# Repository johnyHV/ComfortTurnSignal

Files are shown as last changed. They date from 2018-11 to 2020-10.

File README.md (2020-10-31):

# ComfortTurnSignal

This project is default use for VW Golf MK4 comfort turn signal. 
Schematic and source code it can also be used in another car without comfort turn signal.

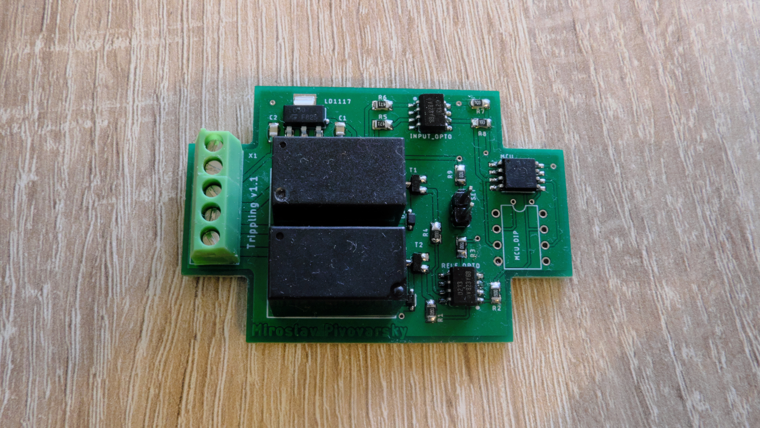
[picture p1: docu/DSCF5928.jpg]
Image description


Youtube video

IMAGE ALT TEXT HERE (https://www.youtube.com/watch?v=xPU7Pdd0vOQ)

# Change log

Version 1.2.1
- HW version 1.2
- SW version 1.4.1

Version 1.2
- HW version 1.2
- SW version 1.4.0

Version 1.1
- HW version 1.1
- SW version 1.3

# Change log SW

Version 1.4.1
- added function, for change blink interval, if is jumper set. Function for this featchure is CheckBlinkIntervalJumper. But if is this function enabled in main.c, then must be definition EEPROM_ENABLE set to 0

Version 1.4.0
- added conf.h file with global MCU configuration
- added debounce time for self calibration SET jumper

Version 1.3.0
- added featchure for disable trippling, when pressing the turn signal control for the opposite direction of flashing

Version 1.2.0
- added fix time for blinking from FLASH memmory

Version 1.1
- Fix bug

Version 1.0
- Init version

# Change log HW

Version 1.2
- update MCU connection
- added SPI programming connector
- added 100nF capacitor for MCU
- added description on the PCB

Version 1.1
- fixed problem with PCB design

Version 1.0
- first version

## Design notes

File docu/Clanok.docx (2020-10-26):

# Trippling – modul komfortného blikania smerových svetiel v aute

Trippling je moderná funkcionalita komfortného blikania smerových svetiel vozidla. Po krátkom stlačení páky smerových svetiel jednotka automaticky 3x blikne daným smerovým svetlom. Elektronika je navrhnutá ako prídavný modul k existujúcemu zapojeniu v automobile, s veľmi jednoduchým zapojením.

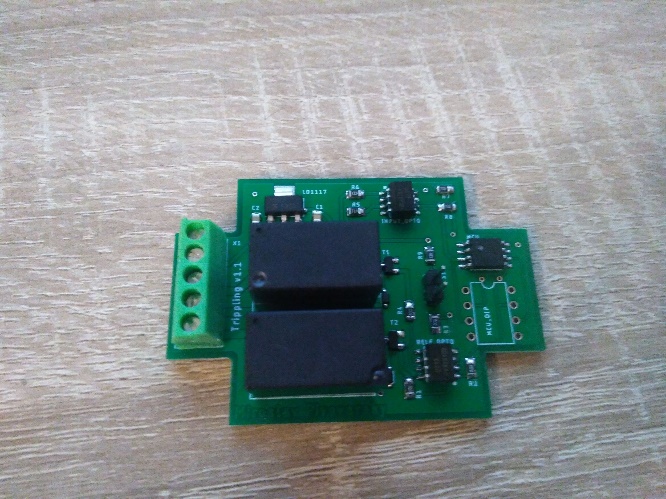
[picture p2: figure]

# Popis

Elektronika v zariadení využíva 5 pinov. Základné piny sú napájanie a zem. Ďalej sú to vstupno / výstupné piny pravého a ľavého smerového svetla a ich COM, čiže spoločný pin. Ak je zaznamenané napätie na ľavom alebo pravom smerovom svetle po určitý časový okamih, elektronika to vyhodnotí ako príkaz pre dokončenie trojitého blikania. Tie isté piny, ktoré detegujú napätie na smerovom svetle, sú použité aj pre spínanie smerových svetiel. Časovač zopnutia smerových svetiel pre trojité blikanie ovláda priamo MCU.

V článku použijem fotografie osadenej HW verzie 1.1, avšak opisovať budem HW verziu 1.2. V HW verzii 1.2 je pridaný blokovací kondenzátor pre MCU, pridaný ISP konektor pre pohodlnejšie programovanie MCU a sú vymenené piny procesora pre spínanie relé, s pinmi procesora, ktoré sledujú stav smerových svetiel. Táto úprava bola potrebná, aby bolo možné naprogramovať osadený MCU na PCB.

# Hardware

Samotné zapojenie pozostáva z MCU ATtiny85, dvoch optočlenov, dvoch RELE a stabilizátora napätia. ATtiny85 je jednoduchý 8 nožničkový MCU s 6 digitálnymi vstupmi/výstupmi, taktovacou frekvenciou 20Mhz bez potreby externého kryštálu. Ďalej obsahuje 8kB Flash pamäte, 512B RAM pamäte a 512B EEPROM pamäte. V tomto MCU vieme vypnúť RESET pin, a využiť ho ako štandardný vstupno/výstupný pin. Potom už musíme MCU programovať pomocou „High voltage programming“ rozhrania.

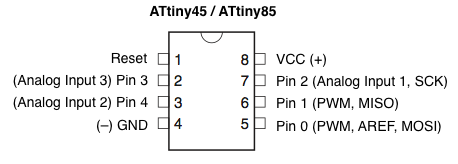
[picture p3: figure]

Návrh PCB je prispôsobený tak, aby všetky SMD súčiastky boli osadené z jednej strany. Pri takomto uložení súčiastok môžeme pre prispájkovanie súčiastok k PCB použiť napríklad žehličku. Spájkovanie žehličkou som opisoval v tomto článku (https://www.elektrolab.eu/blog/osadzanie-smd-suciastok-v-domacom-prostredi-pomocou-zehlicky). Pre nanášanie spájkovacej pasty môžeme použiť podávač spájkovacej pasty. Konštrukciu pre podávač som opísal v tomto článku (https://www.elektrolab.eu/blog/podavac-spajkovacej-pasty-solder-paste-dispenser).

Zoznam súčiastok:

- Attiny85 SOIC8 alebo DIP8 puzdro
- Stabilizátor LD1117 5V, SOT223 puzdro
- 2x optočlen ILD213T, SOIC puzdro
- 2x tranzistor MMBT3904, SOT23 puzdro
- 2x dióda 1N4148, SOD323F puzdro
- 2x relé HF32F/005-ZS, 5V a 5 pinové! (na Slovensku ho predáva napríklad avelmak.sk)
- 4x SMD rezistor 120ohm 0805
- 3x SMD rezistor 10Kohm 0805
- 2x SMD rezistor 470ohm 0805
- 3x SMD kondenzátor 100nF 0805
- 1x 5 pinový konektor PHOENIX 1751277, rozteč 3.5mm (alebo kombinácia 2 pinového a 3 pinového konektora)
- Krabička typu Z-24BU (známa aj ako KPZ 01 AU)

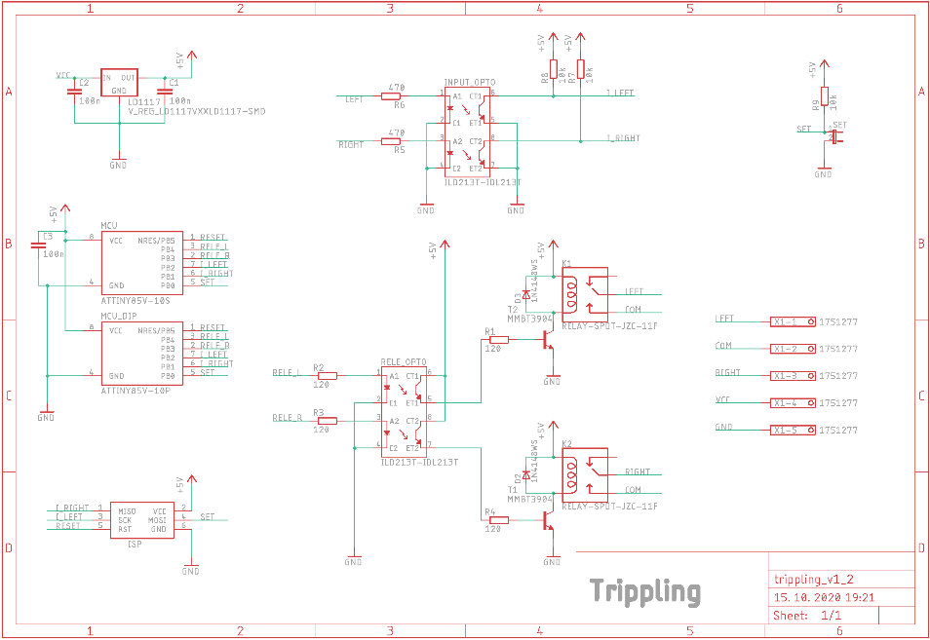
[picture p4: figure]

Schéma zapojenia

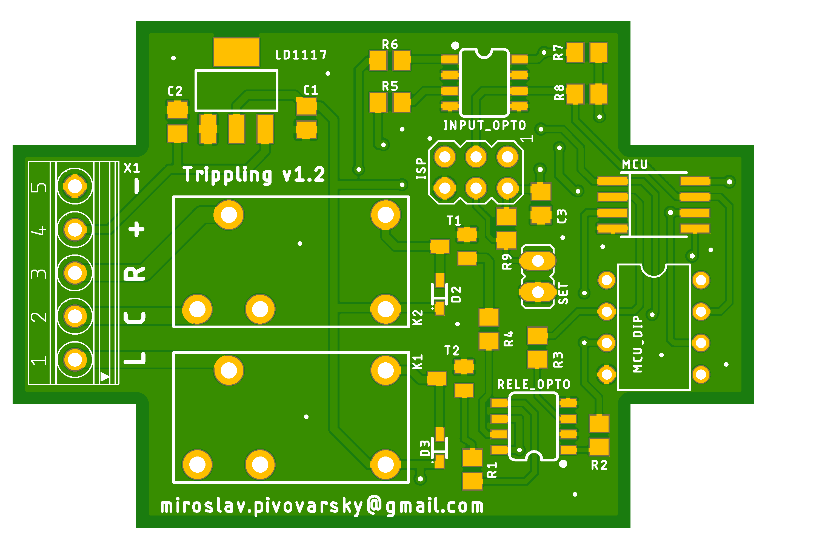
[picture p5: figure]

Vrchná strana PCB

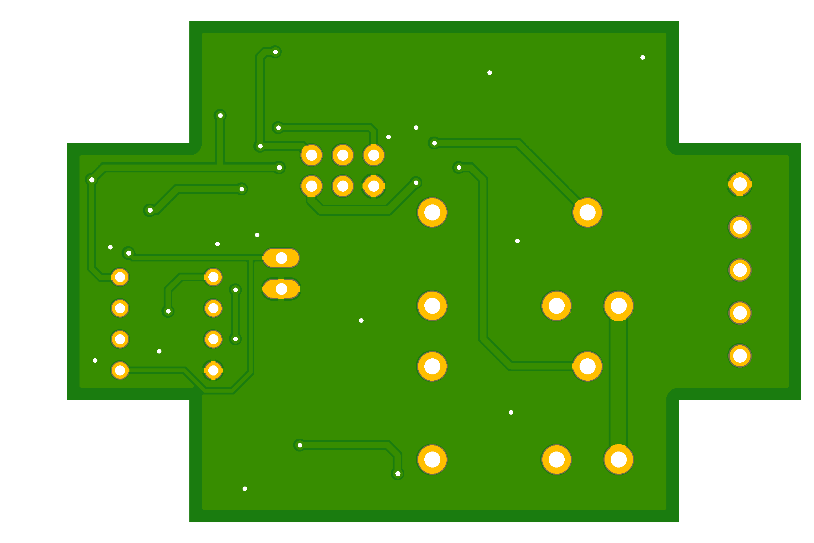
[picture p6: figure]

Spodná strana PCB

# Zapojenie

Pre napájanie elektroniky slúžia piny 4 a 5, označené plus a mínus z konektora X1. Maximálne napájacie napätie je 15V a absolútne maximálne napájacie napätie je 20V. To je pre elektroinštaláciu v bežnom aute postačujúci rozsah. Keďže ideme do automobilu pridať elektroniku neschválenú výrobcom, potrebujeme dodržať pár podmienok, aby sme predišli prípadným problémom počas technickej kontroly STK. Prvou podmienkou je pripojiť elektroniku cez vlastnú poistku. Poistka nemusí byť ľahko prístupná v prípade, že ju bude potrebné vymeniť. Druhá podmienka je, aby bolo možné vzpnúť elektroniku kedykoľvek a jednoducho. Na to je ideálny vypínač, ktorý je v dosahu ruky aj počas jazdy autom. Osobne testujem HW a SW už 2 roky, a funguje bez problémov. Nikto by si určite neželal, aby mu z ničoho nič začali blikať smerové svetlá vďaka HW/SW chybe, a nemohol to žiadnym spôsobom vypnúť. Práve z tohto dôvodu je vhodné mať vypínač vždy na dosah ruky. Ja som umiestnil vypínač zo spodnej strany palubnej dosky, blízko vodičových dverí. Vypínač je na prvý pohľad ukrytý, a súčasne vždy ľahko prístupný aj počas jazdy. Z danej poistky a vypínača, je v mojom prípade súčasne napájaná palubná kamera, cúvacia kamera a elektronika komfortného blikania. Odporúčam elektroniku pripojiť na vetvu KL15, čo je vetva, na ktorej sa objaví 12V až po otočení kľúča do prvej polohy.

Keď už máme elektroniku napájanú, ďalej je potrebné pripojiť elektroniku k smerovým svetlám. Nie je možné napísať univerzálne zapojenie pre všetky typy automobilov, keďže každý automobil ma iné farebné značenie kabeláže, a inú konštrukciu. Ja opíšem moje zapojenie, pre VW Golf 4, no myslím si, že by to malo sedieť pre automobily z koncernu VW Group.

Prvým krokom bolo rozobrať stredový výduch. Skrutky sa ukázali po vybratí plastov, pre smerovanie vyfukovaného vzduchu. Odporúčam dať pozor na gumičky, ktoré sa nachádzajú na výduchoch po oboch stranách. Môže sa stať, že gumičky zapadnú dozadu. Bolo by lepšie mať pri manipulácií s nimi tie výduchy zatvorené. Následne som musel jemne odbaliť kabeláž pre výstražné svetlá, a nájsť správne vodiče.

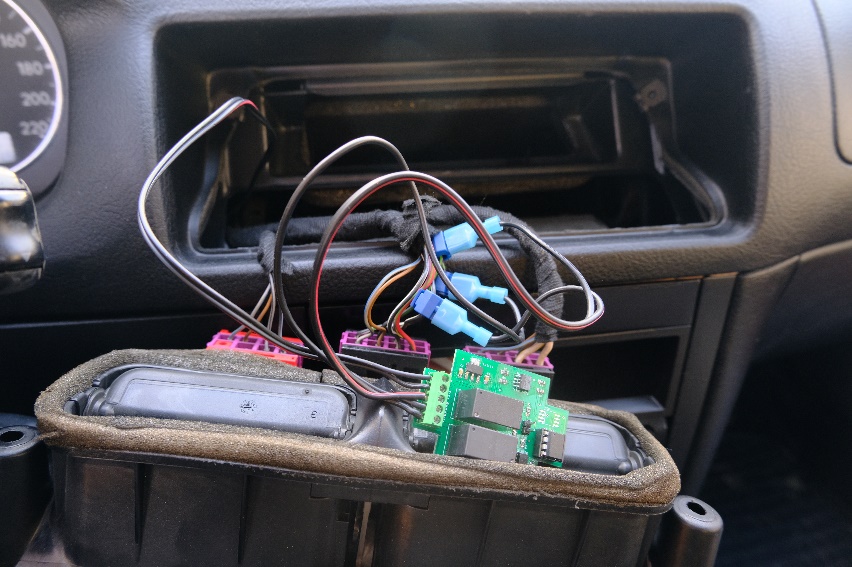
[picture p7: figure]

Pre zapojenie potrebujeme vodič pre ľavé aj pravé smerové svetlo, a ich spoločný vodič. Spoločný vodič je 12V napájacie napätie privedené z poistky pre smerové svetlá z poistkovej skrinky. To platí iba vo vozidlách s kladným ovládacím napätím smerových svietidiel a celej elektroinštalácie v aute. Zariadenie je možné použiť aj vo vozidle so záporným ovládacím napätím, keďže relé spína COM port voči príslušnému smerovému svetlu. Všetky tieto vodiče sa nachádzajú napríklad pri výstražnom tlačidle. Preto som zvolil možnosť pripojenia elektroniky k výstražnému tlačidlu. Súčasne je k výstražnému tlačidlu dotiahnutých 12V pre vetvu KL15 (napájanie na vodiči je až v prvej polohe kľúčika v spínacej skrinke) a zem, no ja som ich nevyužil. V aute mám vlastnú vetvu s 12V napájaním cez poistku a vypínač.

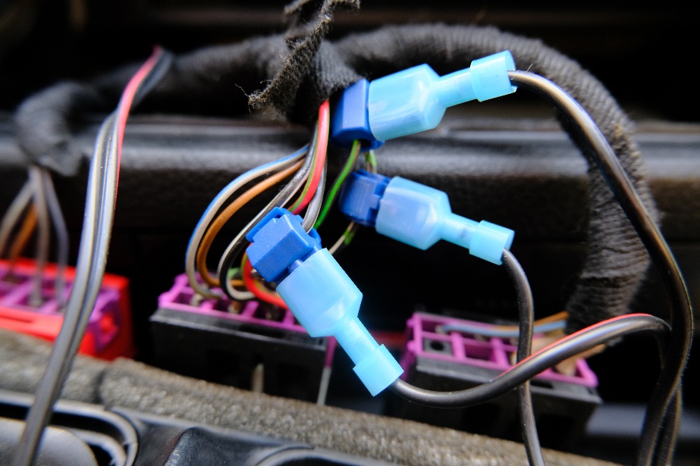
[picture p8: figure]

V nasledujúcej tabuľke opíšem význam farieb vodičov, a ich piny na výstražnom tlačidle pre Golf 4, čo by malo sedieť pre väčšinu áut daného koncernu medzi rokmi 1999-2005.

| Ľavá smerovka | Pravá smerovka | Spoločný kontakt | +12V | ZEM
Farba vodiča | Čierno biely | Čierno zelený | Čierno bielo zelený | Čierno biely | Hnedý
Číslo pinu na spínači | 3 | 2 | 1 | 7 | 6

Pre pripojenie k existujúcej kabeláži som sa snažil využiť najmenej deštruktívnu, a najľahšie rozoberateľnú možnosť. Použil som „T-TAP faston“ konektory. V čínskych e-shopoch sa dajú kúpiť dosť lacno, zvyčajne pod názvom „Snap Splice Lock Wire Terminal Crimp“. Na jednej strane je bočník s nožom, do ktorého sa pripája klasický faston konektor.

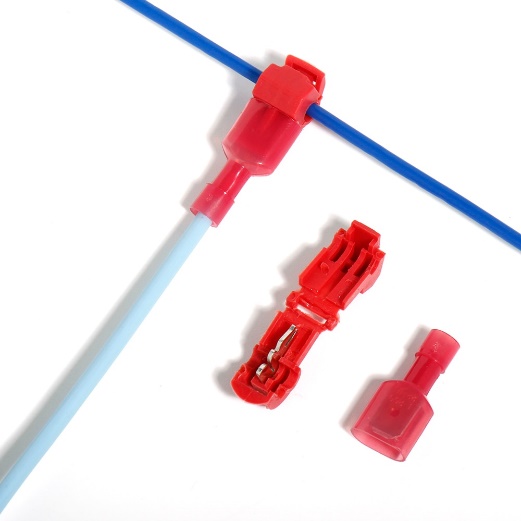
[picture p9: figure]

Vstup a výstup pre ľavú smerovku je na PCB označený písmenom L, pod číslom 1. Vstup a výstup pre pravú smerovku je označený na PCB písmenom R, pod číslo 3. Ako posledný ostal spoločný vodič, čiže COM. Ten je označený písmenom C, pod číslom 2.

Celá elektronika je navrhnutá tak, aby sa zmestila do spomínanej krabičky Z-24BU.

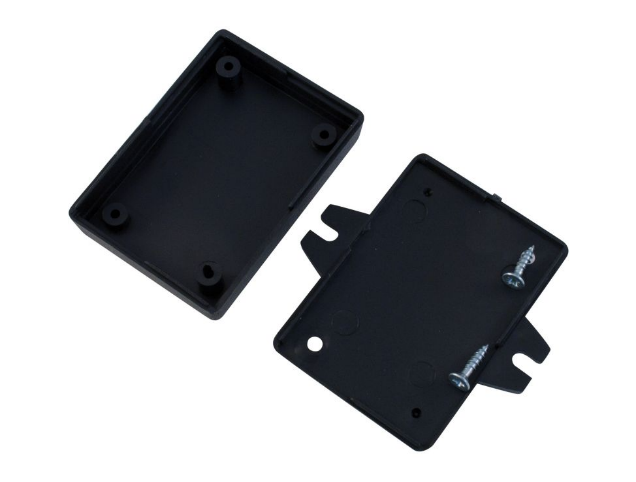
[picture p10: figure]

Po pripojení napájania na pin 4 a uzemnenia cez pin 5, je elektronika ihneď funkčná a aktívna. Procesor neprechádza do žiadneho sleep módu, a nie je v ňom naprogramovaný žiadny power save mód. Preto odporúčam pripojiť elektroniku na vetvu KL15, aby bola elektronika aktívna až po vložení kľúča a pretočení do prvej polohy.

# Ovládanie

Ak je elektronika napájaná, potom automaticky neustále monitoruje smerové svetla. Pre aktiváciu trojitého blikania musíte krátko ťuknúť do páky pre aktiváciu smerového svetla. Pri krátkom ťuknutí elektronika vyhodnotí rozkaz, pre aktiváciu trojitého bliknutia. V prípade, že ste aktivovali trojité blikanie, a rozhodli ste sa zrušiť svoju voľbu, krátko ťuknite do páky pre opačný smer, čím vydáte procesoru príkaz pre núdzové ukončenie jeho činnosti. Elektronika sleduje dĺžku „ťuknutia“ do páky pre smerové svetlá, t.j. sníma dĺžku impulzu pre aktiváciu povelu. V prípade, že sú smerové svetlá zapnuté nad určitý čas (pre príklad viac ako 300ms), procesor to vyhodnotí ako spínanie prerušovačom, ktorý vložil do automobilu výrobca. Z toho dôvodu, aby nezasahoval do oficiálneho cyklovača nevykoná žiadnu operáciu. Takáto situácia môže vzniknúť napríklad pri zapnutí výstražných svetiel, alebo v prípade, keď je páka smerového svetla aretovaná (zapnutá) trvale.

# Software

Zdrojový kód je napísaný v jazyku C, v Atmel Studio 7.0. Existujú 2 verzie zdrojového kódu. Aby si nemusel každý kompilovať zdrojový kód, pridám vykompilované binárne súbory pre oba verzie zdrojového kódu. V MCU je aktivovaný watchdog časovač, pre prípadné problémy.

Prvá verzia pracuje s možnosťou naučenia sa dĺžky zopnutia smerových svietidiel a následné uloženie hodnoty do EEPROM pamäte. Táto možnosť sa mi úplne neosvedčila. V jednom prípade sa mi stala situácia, kedy sa EEPROM pamäť prepísala. Mohlo sa to stať zákmitom, na jumpri počas štartovania auta. Aktuálne je už jumper ošetrený proti zákmitu. V tejto verzii zdrojového kódu odpojíme elektroniku od napájania, prepojíme jumper SET prepojkou, pripojíme napájacie napätie na elektroniku. Následne zapneme smerové svetlá pre ľavú stranu. Necháme chvíľu blikať smerové svetlá, a potom ich vypneme. Následne vypneme napájacie napätie pre elektroniku, a vyberieme prepojku pre jumper SET. Touto sekvenciou sme elektroniku naučili časový interval blikania prerušovača v automobile. Tento firmware nájdete pod názvom trippling_self_calibration_v1_4_0.hex

V druhej verzii si nastavíme fixnú hodnotu dĺžky zapnutia smerových svetiel, a pomocou tejto hodnoty skompilujeme zdrojový kód. Vďaka tomu sa stane hodnota konštantou, uloženou vo FLASH pamäti, ktorá je v princípe neprepisovateľná (neberiem v úvahu extrémne situácie). Tento firmware nájdete pod názvom trippling_fix_time_v1_4_0.hex, s pevne definovaným časom dĺžky zapnutia smerových svetiel 400ms a trojitým blikaním. V tomto zdrojovom kóde musí byť ťuknutie do páky pre smerové svetlá dlhšie ako 80ms ale kratšie ako 300ms.

V zdrojovom kóde sa nachádza súbor Conf.h pre konfiguráciu MCU a jednotlivých funkcionalít. Definícia BLINK_INTERVAL určuje počet bliknutí, aktuálne je táto hodnota nastavená na 3 bliknutia, ale môžete si ju nastaviť na ľubovoľný počet. Dĺžku času, kedy je celé zariadenie neaktívne po núdzovom vypnutí môžeme nastaviť pomocou premennej SAFETY_DELAY, ktorá je aktuálne nastavená na 500ms. Dĺžku zopnutia a vypnutia smerových svetiel počas blikania môžeme nastaviť v zdrojovom kóde pomocou premennej TIME_ON_OFF_LENGTH. Táto premenná sa používa iba v tom prípade, kedy využívate pevne nastavený čas blikania z FLASH pamäte. V prípade, že chcete používať EEPROM pamäť pre dynamickú zmenu dĺžky blikania, je potrebné v súbore Conf.h nastaviť definíciu EEPROM_ENABLE na hodnotu 1. Časový interval, počas ktorého ak buchneme do páky pre smerové svetlá, bude aktivované trojité blikanie, je vypočítaný automaticky na 80% z času blikania v prípade, ak použijete EEPROM pamäť. Ak použijete pevnú definíciu vo FLASH pamäti, potom tieto intervaly môžeme nastaviť pomocou definícií TIMEOUT_ENABLE_BULB a MIN_TIME_FOR_EN_TRIPP. Pričom definícia TIMEOUT_ENABLE_BULB vraví o maximálnej dĺžke zopnutia páky, v tomto prípade 300ms a definícia MIN_TIME_FOR_EN_TRIPP vraví o minimálnej dobe zopnutia páky, v tomto prípade 80ms. Minimálna doba je pridaná z dôvodu auto diagnostiky vypálenej žiarovky v niektorých automobiloch.

Nastavenie poistiek pre MCU ATtiny85 je následovné:

Extended: 0xFF

HIGH: 0xD7

LOW: 0xE2

LOCKBIT: 0xFF

Prikladám aj screenshoty nastavenia poistiek z AVR štúdia

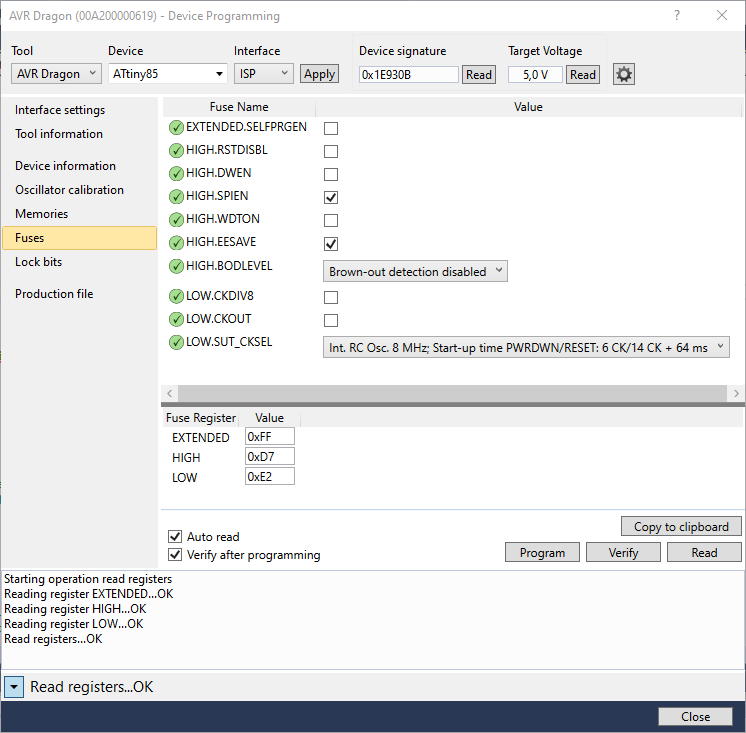
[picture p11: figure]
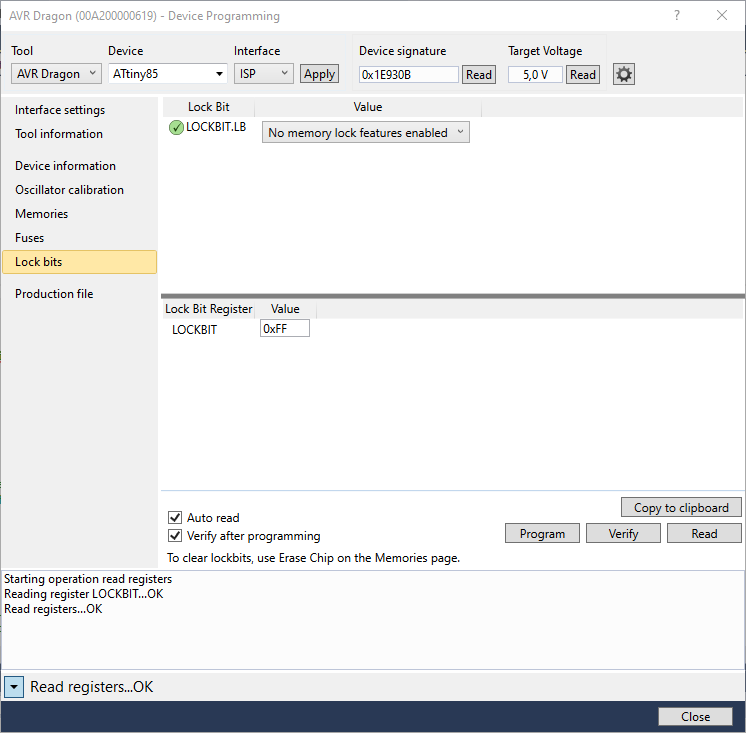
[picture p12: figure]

Pre nahratie binárneho súboru môžete použiť napríklad AVRDUDE v kombinácii s AVRDUDESS. AVRDUDE je konzolový SW pre nahrávanie binárneho súboru pomocou programátora do MCU, a AVRDUDESS je grafická nadstavba pre AVRDUDE. Môžeme ho stiahnuť napríklad zo stránky https://blog.zakkemble.net/avrdudess-a-gui-for-avrdude/ . Ako programátor používam USBasp debuger k AVRDUDE a AVR dragon k atmel studiu. AVR dragon podporuje rozšírené možnosti, napríklad možnosť debugovania SW v bežiacom MCU. USBasp je lacný programátor, ktorý viete kúpiť aj v čínskom e-shope alebo si ho vyrobiť pomocou Arduina. Osobne sa mi z lacných programátorov najviac osvedčil USBasp programátor pre Atmel MCU. Nastavenie AVRDUDESS by v tomto prípade vyzeralo následovne:

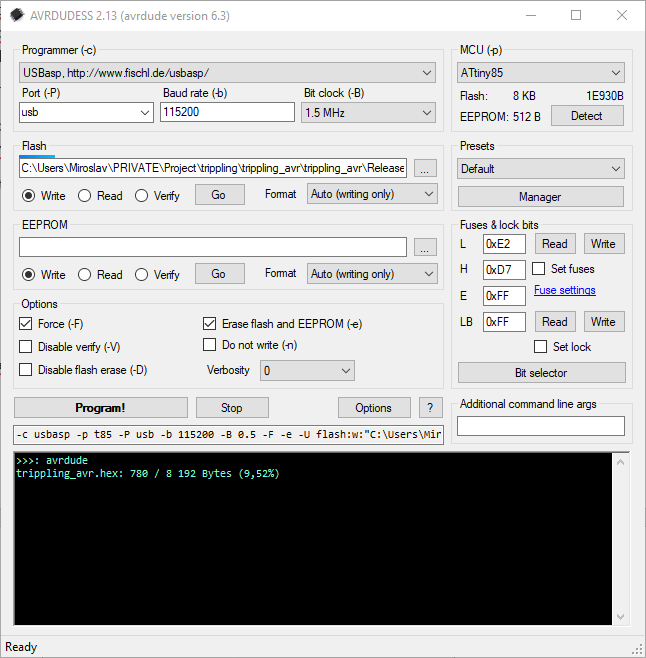
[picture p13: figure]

Niekedy sa môže stať, že pri kúpe nového procesora ATtiny85 ho musíme prvý krát pripojiť pomocou rozhrania „High Voltage programming“ k programátoru, a nastaviť mu správne poistky. Vytvoriť si vlastný „High voltage“ programátor je už trochu náročnejšie, práve preto využívam originálny programátor AVR dragon. V prípade záujmu viem upraviť konfiguráciu zdrojového kódu podľa požiadaviek, a nahrať vykompilovaný zdrojový kód do MCU ATtiny85. Toto zapojenie viete použiť aj ako dvojkanálový prerušovač pri menšej úprave zdrojového kódu.

# Odkazy

Zdrojový kód, potrebné knižnice, návrh PCB, schému a všetky potrebné podklady + podklady pre výrobu PCB nájdete v mojom git repozitári https://github.com/johnyHV/ComfortTurnSignal . Video s ukážkou funkčnosti nájdete na YouTube https://youtu.be/xPU7Pdd0vOQ

# Kontakt

miroslav.pivovarsky@gmail.com

Ďakujem za prečítanie článku, dúfam že vás konštrukcia zaujala.

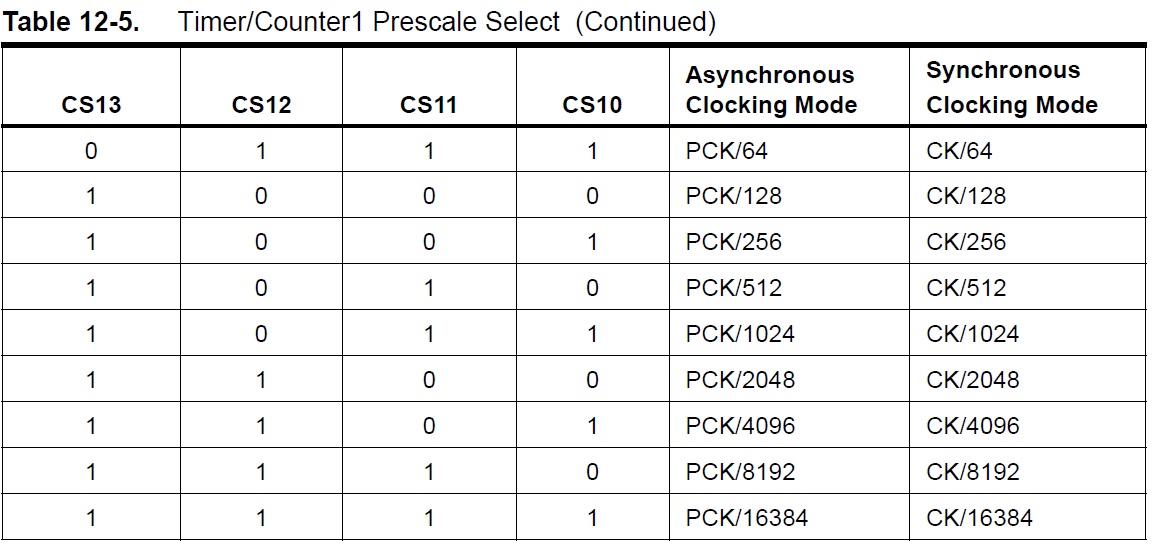
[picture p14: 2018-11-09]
trippling_avr/ZHCAl30.png

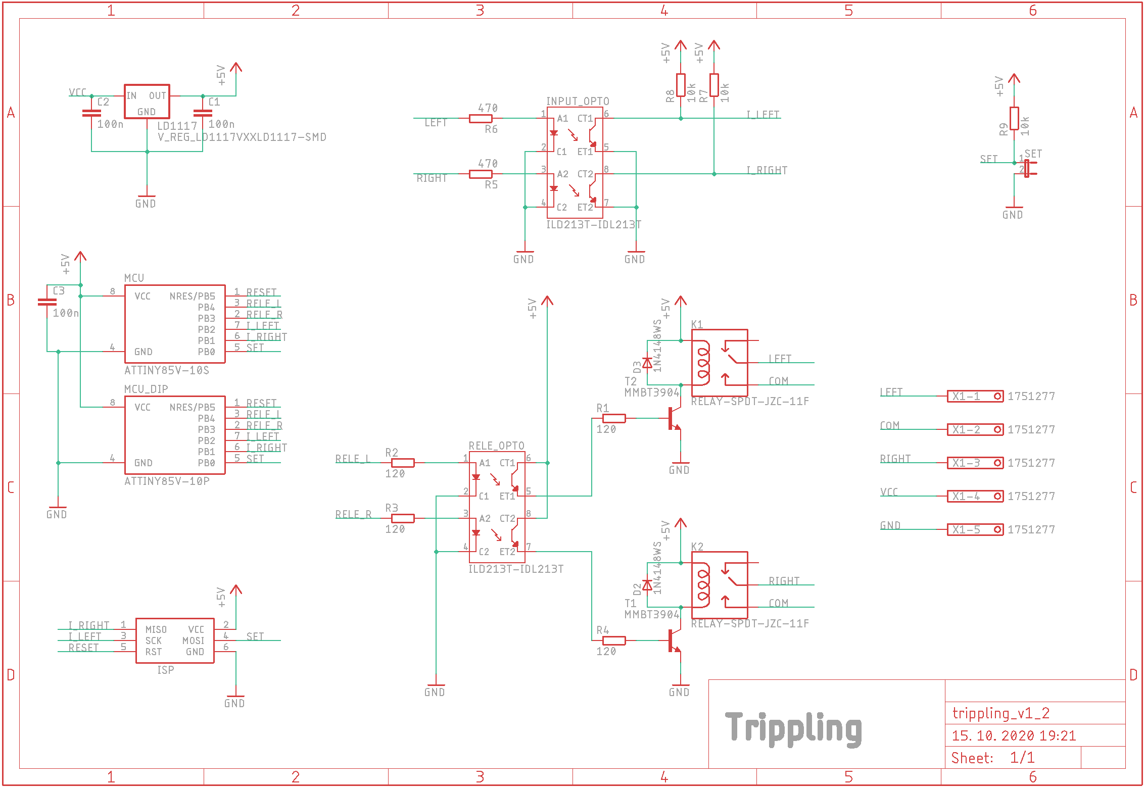
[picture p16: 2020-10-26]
docu/schema.png

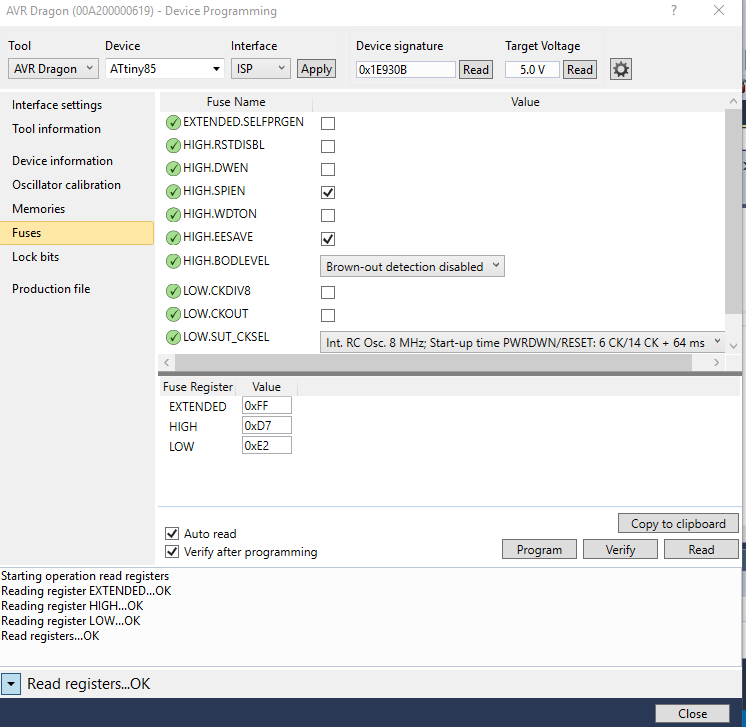
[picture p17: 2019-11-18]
trippling_avr/Register.png

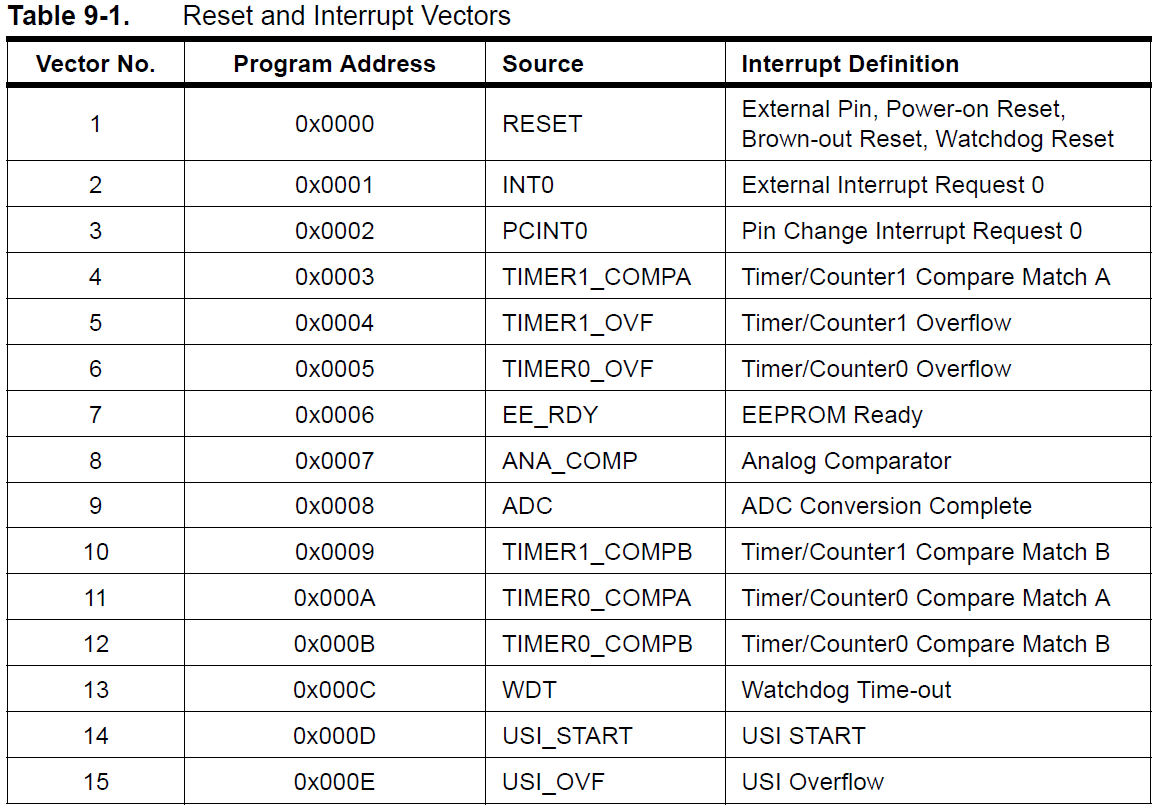
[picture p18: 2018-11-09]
trippling_avr/n6yTYwl.png

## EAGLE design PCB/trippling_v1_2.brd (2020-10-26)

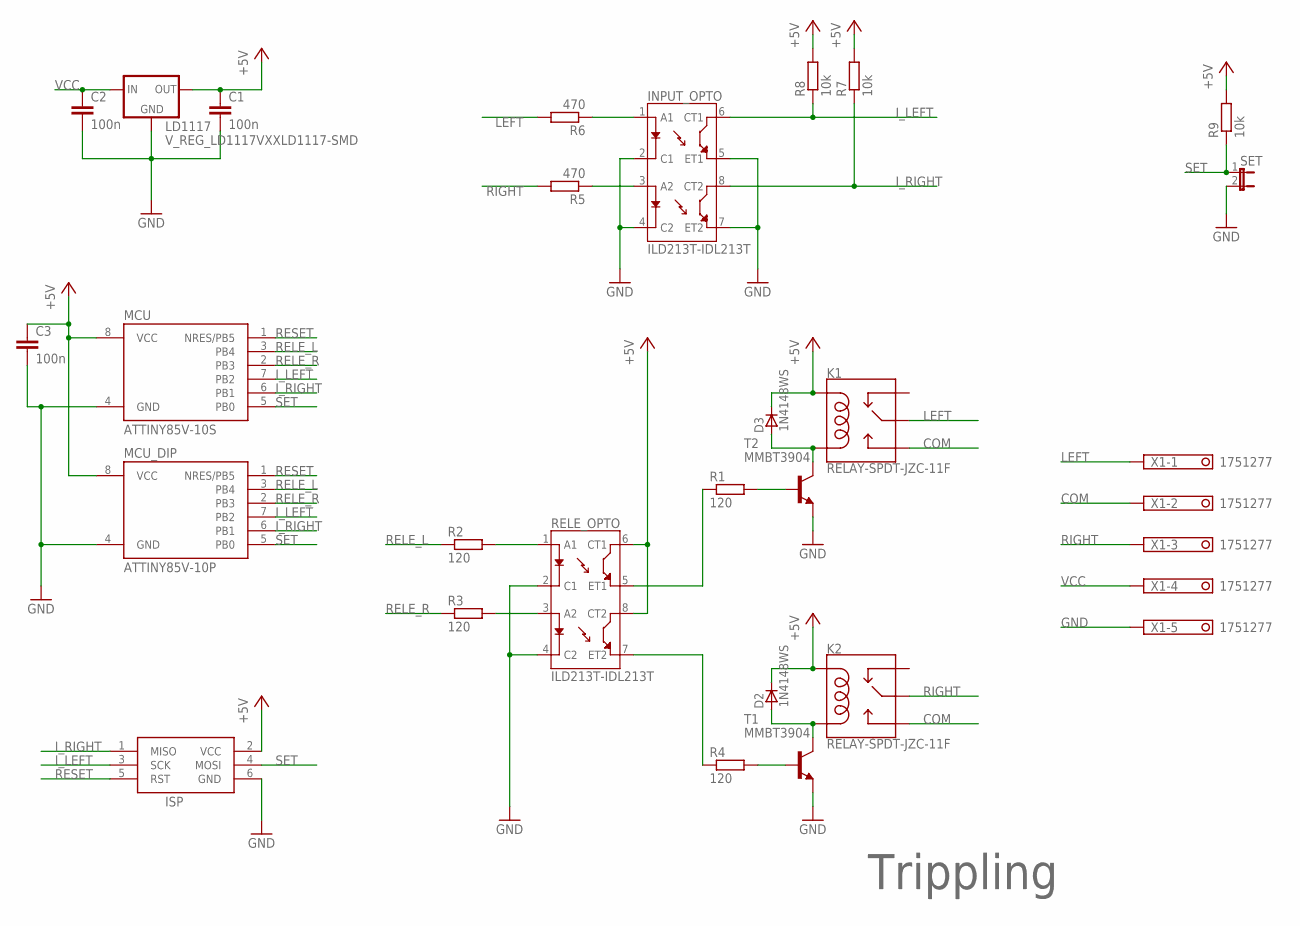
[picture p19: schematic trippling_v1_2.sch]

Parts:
C1, C2, C3: 100n; C0805
D2, D3: 1N4148WS; SOD323F
INPUT_OPTO: ILD213T-IDL213T; SO08
ISP: AVRISP-6; AVRISP
K1, K2: RELAY-SPDT-JZC-11F; RELAY-JZC
LD1117: V_REG_LD1117VXXLD1117-SMD; SOT223
MCU: ATTINY85V-10S; SOIC8_EIAJ_208MIL
MCU_DIP: ATTINY85V-10P; PDIP08_300MIL
R1, R2, R3, R4: 120; R0805
R5, R6: 470; R0805
R7, R8, R9: 10k; R0805
RELE_OPTO: ILD213T-IDL213T; SO08
SET: JP1E; JP1
T1, T2: MMBT3904; SOT23-BEC
X1: 1751277

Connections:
+5V: C1.1, C3.1, D2.C, D3.C, ISP.2 (VCC), K1.5 (COIL1), K2.5 (COIL1), LD1117.2 (OUT), MCU.8 (VCC), MCU_DIP.8 (VCC), R7.2, R8.2, R9.2, RELE_OPTO.6 (CT1), RELE_OPTO.8 (CT2)
COM: K1.3 (NO), K2.3 (NO), X1.2
GND: C1.2, C2.2, C3.2, INPUT_OPTO.2 (C1), INPUT_OPTO.4 (C2), INPUT_OPTO.5 (ET1), INPUT_OPTO.7 (ET2), ISP.6 (GND), LD1117.1 (GND), MCU.4 (GND), MCU_DIP.4 (GND), RELE_OPTO.2 (C1), RELE_OPTO.4 (C2), SET.2, T1.E, T2.E, X1.5
I_LEFT: INPUT_OPTO.6 (CT1), ISP.3 (SCK), MCU.7 (PB2), MCU_DIP.7 (PB2), R8.1
I_RIGHT: INPUT_OPTO.8 (CT2), ISP.1 (MISO), MCU.6 (PB1), MCU_DIP.6 (PB1), R7.1
LEFT: K1.4 (MAIN), R6.2, X1.1
unnamed: INPUT_OPTO.1 (A1), R6.1
unnamed: INPUT_OPTO.3 (A2), R5.1
unnamed: D3.A, K1.1 (COIL2), T2.C
unnamed: R1.2, T2.B
unnamed: R4.2, T1.B
unnamed: D2.A, K2.1 (COIL2), T1.C
unnamed: R1.1, RELE_OPTO.5 (ET1)
unnamed: R4.1, RELE_OPTO.7 (ET2)
unnamed: R3.2, RELE_OPTO.3 (A2)
unnamed: R2.2, RELE_OPTO.1 (A1)
RELE_L: MCU.3 (PB4), MCU_DIP.3 (PB4), R2.1
RELE_R: MCU.2 (PB3), MCU_DIP.2 (PB3), R3.1
RESET: ISP.5 (RST), MCU.1 (NRES/PB5), MCU_DIP.1 (NRES/PB5)
RIGHT: K2.4 (MAIN), R5.2, X1.3
SET: ISP.4 (MOSI), MCU.5 (PB0), MCU_DIP.5 (PB0), R9.1, SET.1
VCC: C2.1, LD1117.3 (IN), X1.4

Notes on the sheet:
Trippling

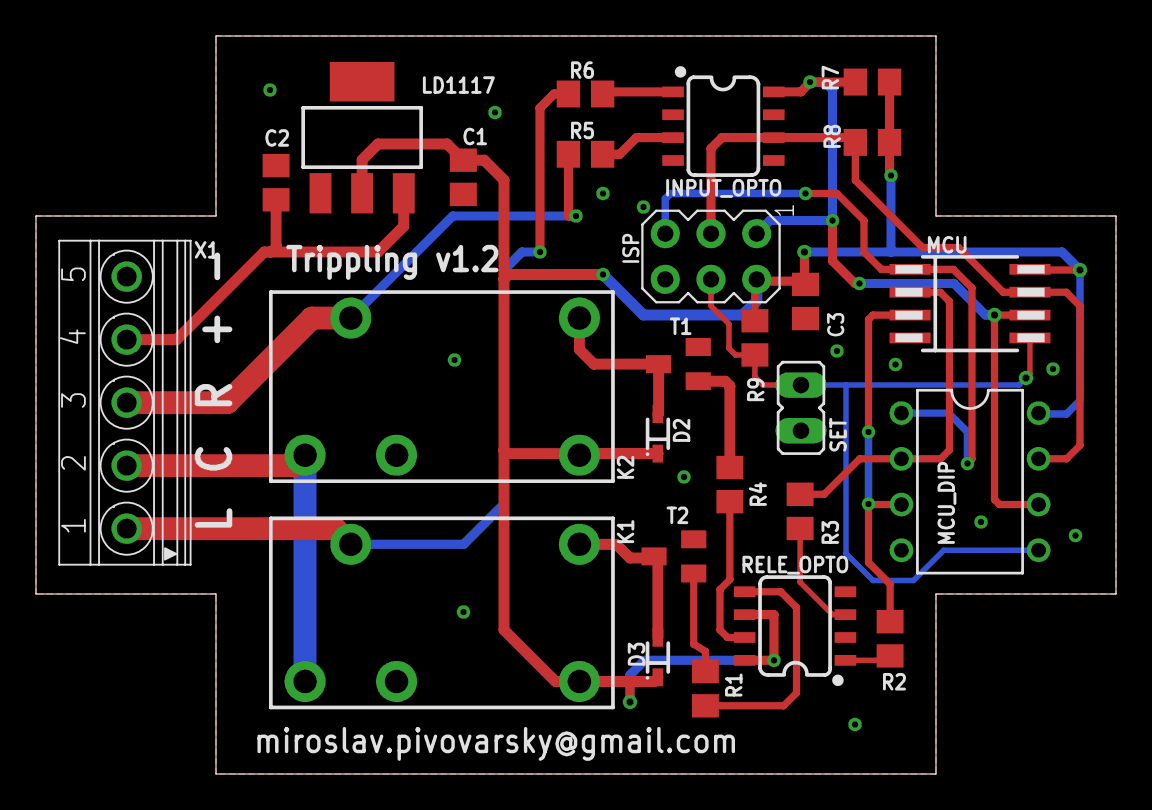
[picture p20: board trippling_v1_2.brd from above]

Board: 2 copper layers, 60.0 x 41.0 mm, 26 parts (0 on the bottom side), 22 nets.

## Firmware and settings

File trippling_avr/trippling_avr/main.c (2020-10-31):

/** @file trippling_avr.c
 *  @brief A System function
 *
 *  Main function
 * 
 *  https://embeddedthoughts.com/2016/06/06/attiny85-introduction-to-pin-change-and-timer-interrupts/
 *
 *  @date 10/31/2018 13:28:07
 *  @author Miroslav Pivovarsky (mpivovarsky)
 *  @version 0.1
 *  @bug No know bugs.
 */

#define F_CPU 8000000 //8.0Mhz/8 = 1.0Mhz

#include <avr/io.h>
#include <avr/wdt.h>
#include <avr/interrupt.h>
#include <avr/eeprom.h>
#include <util/delay.h>

#include "Init.h"
#include "Task.h"
#include "Variable.h"

int main(void)
{
	MCUSR = 0;
	wdt_disable();
	
	initGpioPin();
	//initTimer1();
	//initInterrupt();
	//WriteTime(TimeForFlashing); // For manual first init Time 
	//CheckBlinkIntervalJumper();
	#if (EEPROM_ENABLE == 1)
	ReadTime();
	CheckSetButton();
	#endif
	
	wdt_reset();
	wdt_enable(WDTO_1S);
	
	while(1)
	{
		CheckButton();
		Flashing();
		_delay_ms(REFRESH_TIME);
		wdt_reset();
	}
}

/** @brief ISR
 *
 *  Callback Function for Timer1 Comparator A
 *
 *  @param TIMER1_COMPA_vect
 *  @return void
*/
ISR(TIMER1_COMPA_vect)
{
	//PINB |= _BV(PINB4);         //flash the LED by toggling PB4
	TCNT1 = 0;
}

/** @brief ISR
 *
 *  Callback Function for Timer1 Comparator B
 *
 *  @param TIMER1_COMPB_vect
 *  @return void
*/
ISR(TIMER1_COMPB_vect)
{
	//PINB |= _BV(PINB3);
}

/** @brief ISR
 *
 *  Callback Function for pin interrupt
 *
 *  @param PCINT0_vect
 *  @return void
*/
ISR(PCINT0_vect)
{
	/* GPIO interrupt */
}

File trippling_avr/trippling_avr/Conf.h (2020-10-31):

/*
 * Conf.h
 *
 * Created: 15. 10. 2020 8:21:08
 *  @author Miroslav Pivovarsky (mpivovarsky)
 *  @version 0.1
 *  @bug No know bugs.
 *
 */ 

#ifndef CONF_H_
#define CONF_H_

#include <avr/io.h>

#define SOFTWARE_VERSION		"1.4.1"	///< Software version
#define HARDWARE_VERSION		12		///< hardware version 1.1 or 1.2

#define F_CPU 8000000					///< 8.0Mhz/8 = 1.0Mhz

#if (HARDWARE_VERSION == 12)
#define INPUT_LEFT				PB2		///< LEFT input
#define INPUT_RIGHT				PB1		///< RIGHT input
#define INPUT_SET_BUTTON		PB0		///< configuration button input
#define RELE_LEFT				PB4		///< LEFT rele
#define RELE_RIGHT				PB3		///< RIGHT rele
#endif

#if (HARDWARE_VERSION == 11)
#define INPUT_LEFT				PB4		///< LEFT input
#define INPUT_RIGHT				PB3		///< RIGHT input
#define INPUT_SET_BUTTON		PB0		///< configuration button input
#define RELE_LEFT				PB2		///< LEFT rele
#define RELE_RIGHT				PB1		///< RIGHT rele
#endif

#define EEPROM_ENABLE			0		///< Enable/disable EEPROM memmory
#define EEPROM_TIME_FLASHING	0x00	///< EEPROM address for store uint16 value for time BULB ON and OFF
#define BLINK_INTERVAL			3		///< triple flash interval
#define REFRESH_TIME			5		///< Refres time for super loop
#define SAFETY_DELAY			500		///< Safety timer
#define TIME_ON_OFF_LENGTH		400		///< timer for length bulb on and off
#define TIMEOUT_ENABLE_BULB		300		///< timeout for enable turn ON bulb
#define MIN_TIME_FOR_EN_TRIPP	80		///< Minimum time for enable trippling

#define TRUE 1							///< True value
#define FALSE 0							///< False value
#define BULB_ON TRUE					///< Bulb on value
#define BULB_OFF FALSE					///< Bulb off value

#endif /* CONF_H_ */

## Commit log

2019-11-18 Fix HW pinout Fix SW pinout add documentation for AVR dragon
    [trippling.brd, trippling.sch]
2020-10-26 [PCB]
    - update original PCB
2020-10-26 [PCB]
    - add version 1.2
    - update MCU connection
    - add SPI programming connector
    - add 100nF capacitor for MCU
    - add description
    [trippling_v1_2.brd, trippling_v1_2.sch]
2020-10-26 [SW]
    - update SW for PCB version 1.2
    - fix typo
    - create Conf.h for MCU global configuration
    [Conf.h, Task.c, main.c]

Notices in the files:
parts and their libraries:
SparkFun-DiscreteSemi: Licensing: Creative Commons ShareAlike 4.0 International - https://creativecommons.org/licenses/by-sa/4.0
